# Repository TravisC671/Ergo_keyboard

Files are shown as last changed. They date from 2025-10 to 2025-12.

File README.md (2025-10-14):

# Items:

- Nice!Nano
- [Gateron Low Profile Switches](https://nuphy.com/collections/switches/products/nuphy-cowberry-l45-low-profile-switches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) + hot swap sockets
- [SK6812-E](https://www.adafruit.com/product/4960) LEDs for backlights
- [5050 neo pixels](https://www.adafruit.com/product/1655?srsltid=AfmBOopqWsB4EftkAqg0JuHwXmVD_hztu0RKxe1mnu9E2U61rxwC4aL4) for case lighting

and more that I'll figure out later

[KiCanvas link](https://kicanvas.org/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)

note the footprints are still a work in progress so nothing is final

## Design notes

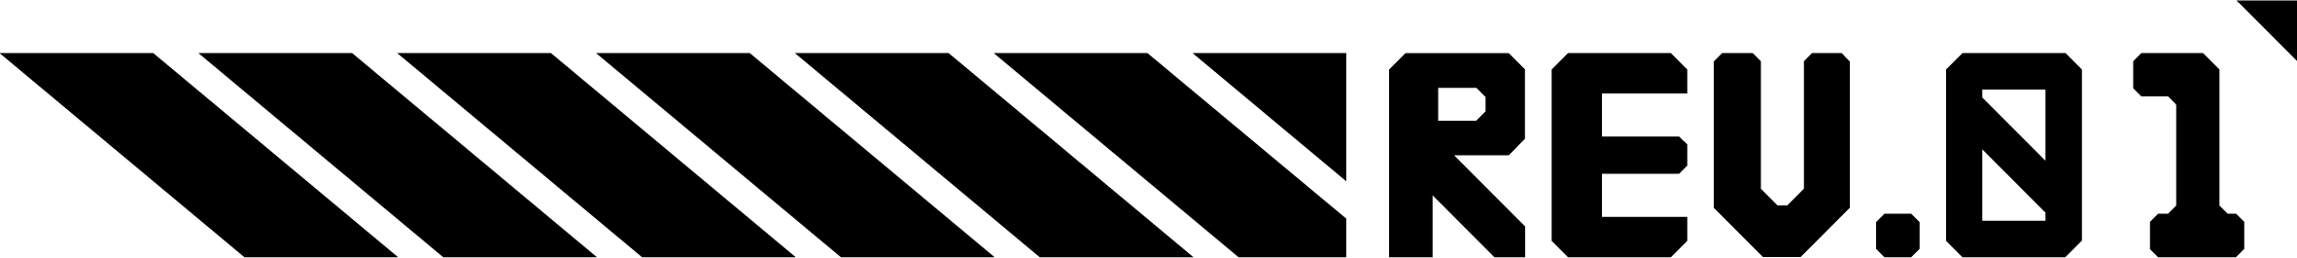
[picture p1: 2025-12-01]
assets/rev_graphic.png

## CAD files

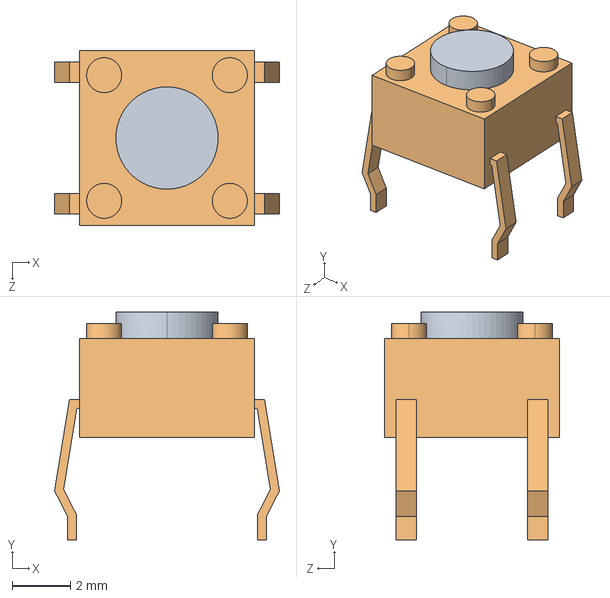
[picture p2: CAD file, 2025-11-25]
ergogen/kicad/B3F_1000/B3F-1000.step
7.70 x 7.80 x 6.00 mm
B3F_1000_BUTTON
B3F_1000_BASE

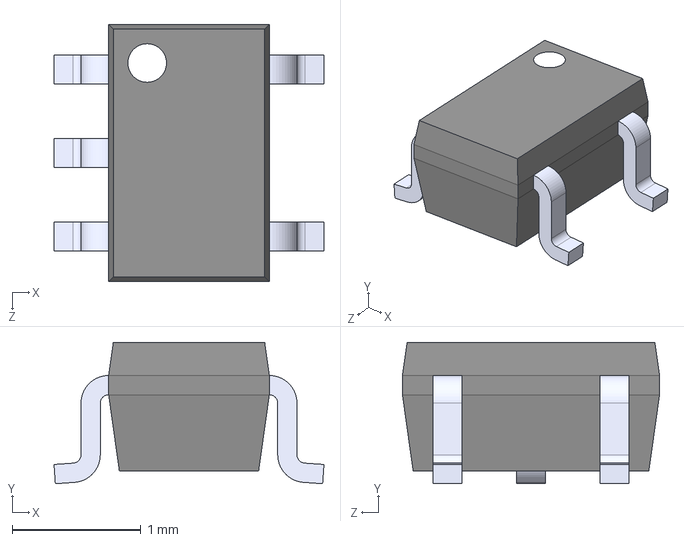
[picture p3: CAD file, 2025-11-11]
ergogen/kicad/SN74LV1T34/SN74LV1T34DCKR.step
2.10 x 1.10 x 2.00 mm

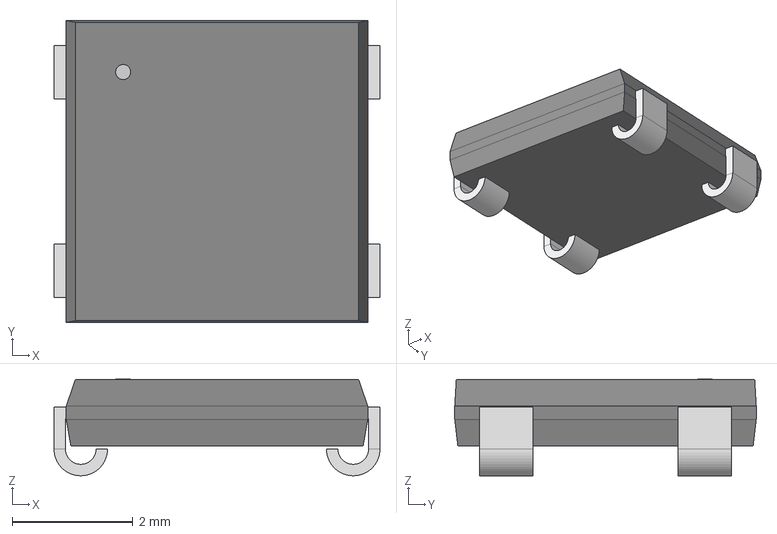
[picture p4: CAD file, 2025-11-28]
ergogen/models/ws2812b.stp
5.41 x 5.00 x 1.60 mm

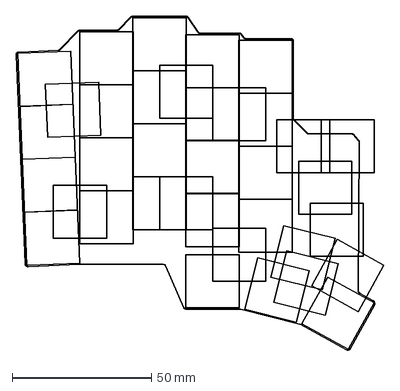
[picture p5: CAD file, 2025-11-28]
output/outlines/view.dxf
131.9 x 119.9 mm

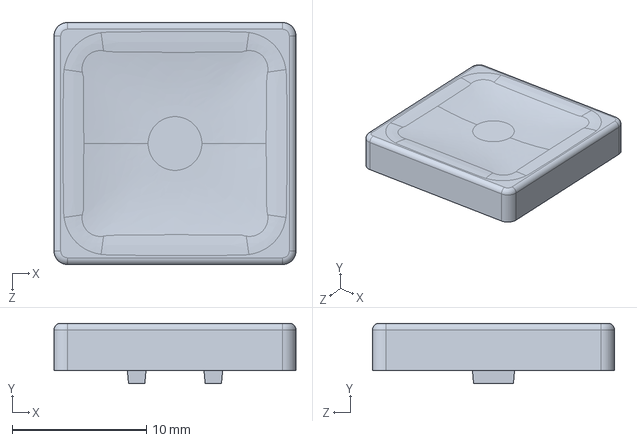
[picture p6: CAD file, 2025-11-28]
ergogen/models/keycap.stp
18.0 x 4.50 x 18.0 mm

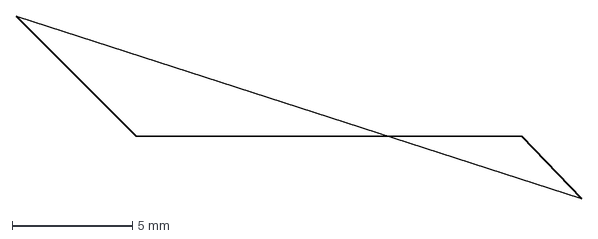
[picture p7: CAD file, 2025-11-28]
output/outlines/mcu_cover.dxf
23.6 x 7.60 mm

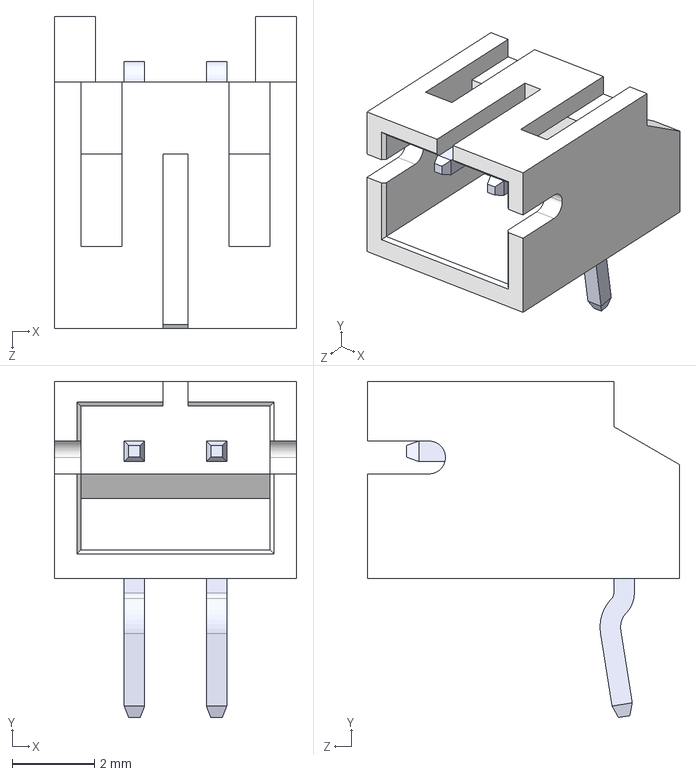
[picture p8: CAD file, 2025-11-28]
ergogen/models/battery_connector.stp
5.90 x 8.18 x 7.60 mm

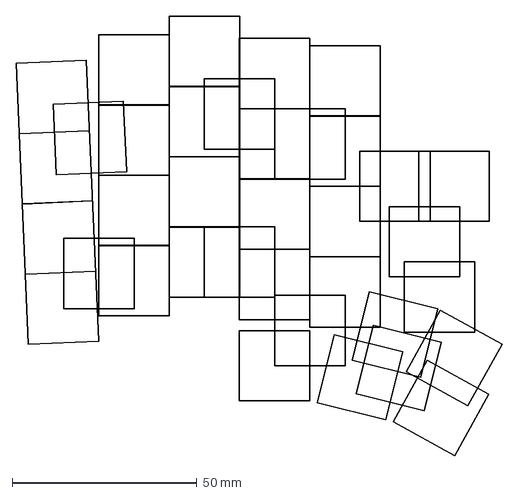
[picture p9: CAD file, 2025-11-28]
output/outlines/keys.dxf
131.4 x 118.9 mm

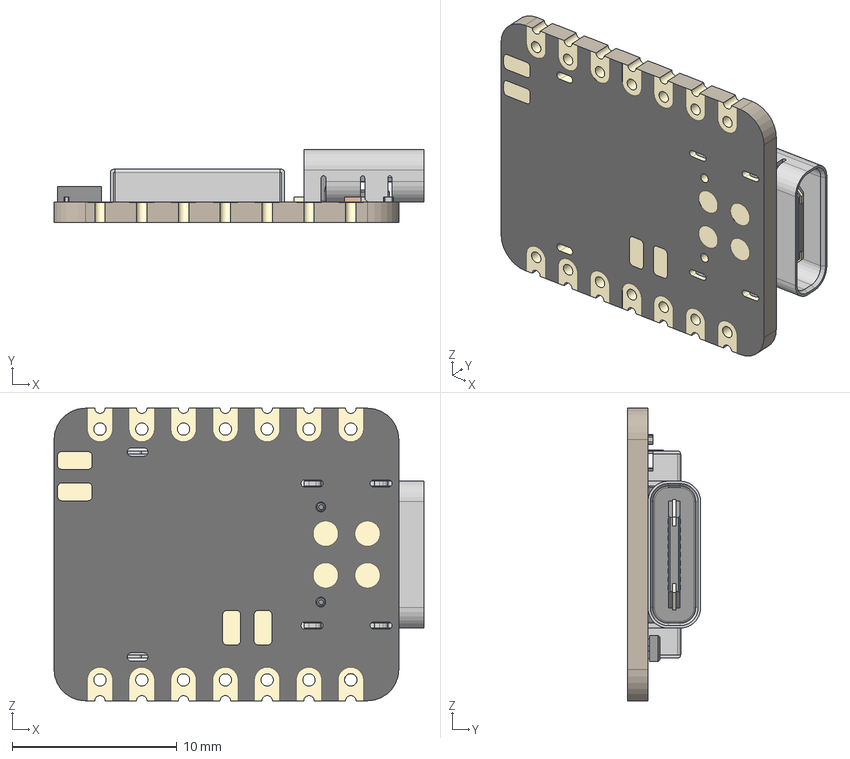
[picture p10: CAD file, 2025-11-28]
ergogen/models/XIAO-nRF52840.stp
22.5 x 4.46 x 17.8 mm
BOSS-EXTRUDE14_8_
BOSS-EXTRUDE7_4_
BOSS-EXTRUDE7_3_
BOSS-EXTRUDE14_4_
BOSS-EXTRUDE14_2_
BOSS-EXTRUDE14_11_
BOSS-EXTRUDE7_7_
BOSS-EXTRUDE14_9_
BOSS-EXTRUDE14_3_
BOSS-EXTRUDE14_7_
MIRROR2
BOSS-EXTRUDE14_5_
BOSS-EXTRUDE14_12_
BOSS-EXTRUDE7_8_
BOSS-EXTRUDE7_1_
BOSS-EXTRUDE14_10_
BOSS-EXTRUDE7_9_
BOSS-EXTRUDE14_6_
BOSS-EXTRUDE14_1_
BOSS-EXTRUDE7_6_
BOSS-EXTRUDE7_2_
CUT-EXTRUDE5
BOSS-EXTRUDE7_5_
Shield
Pins
CAP x 2
ANT1
Silkscreen
CAP 3
LED
USR
2 v1

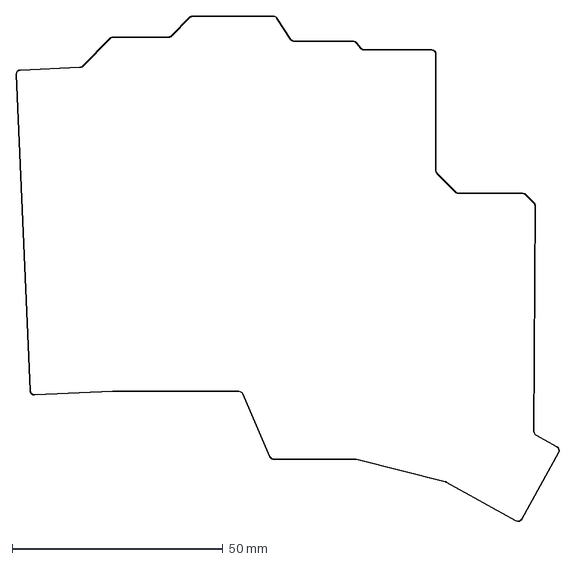
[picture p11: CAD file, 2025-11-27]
output/outlines/pcb_outline.dxf
128.8 x 119.9 mm

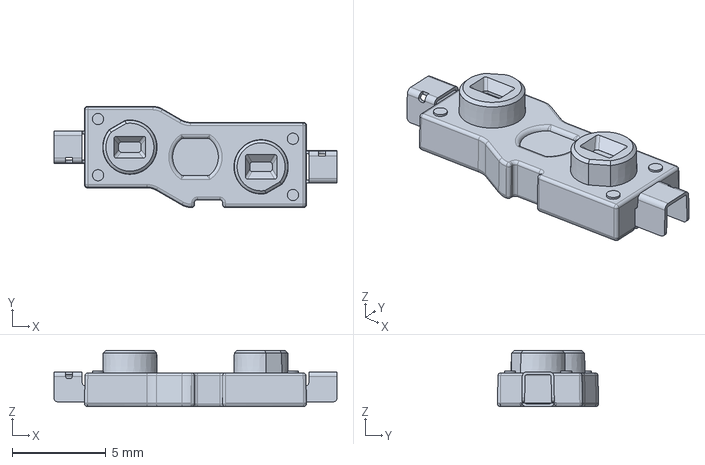
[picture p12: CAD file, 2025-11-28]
ergogen/models/low_profile_hotswap.stp
15.1 x 5.39 x 3.00 mm

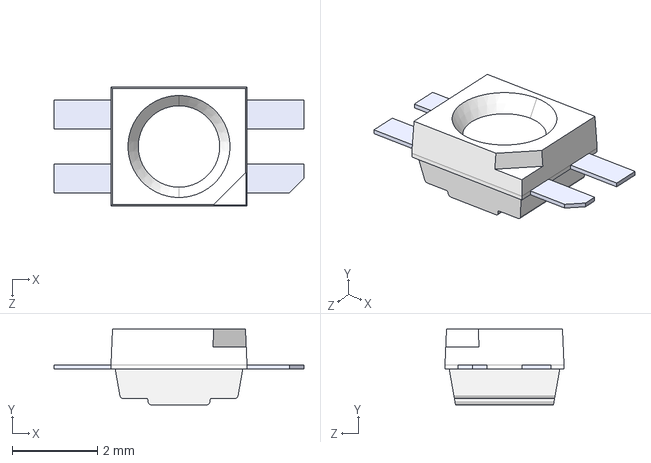
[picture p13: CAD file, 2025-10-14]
ergogen/models/SK6812-E.stp
5.88 x 1.78 x 2.80 mm

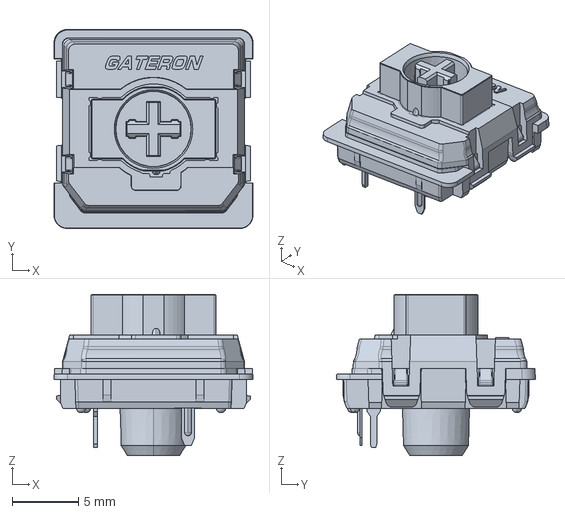
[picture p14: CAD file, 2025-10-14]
ergogen/models/KS-33_lp_2.0.stp
15.0 x 15.0 x 12.1 mm

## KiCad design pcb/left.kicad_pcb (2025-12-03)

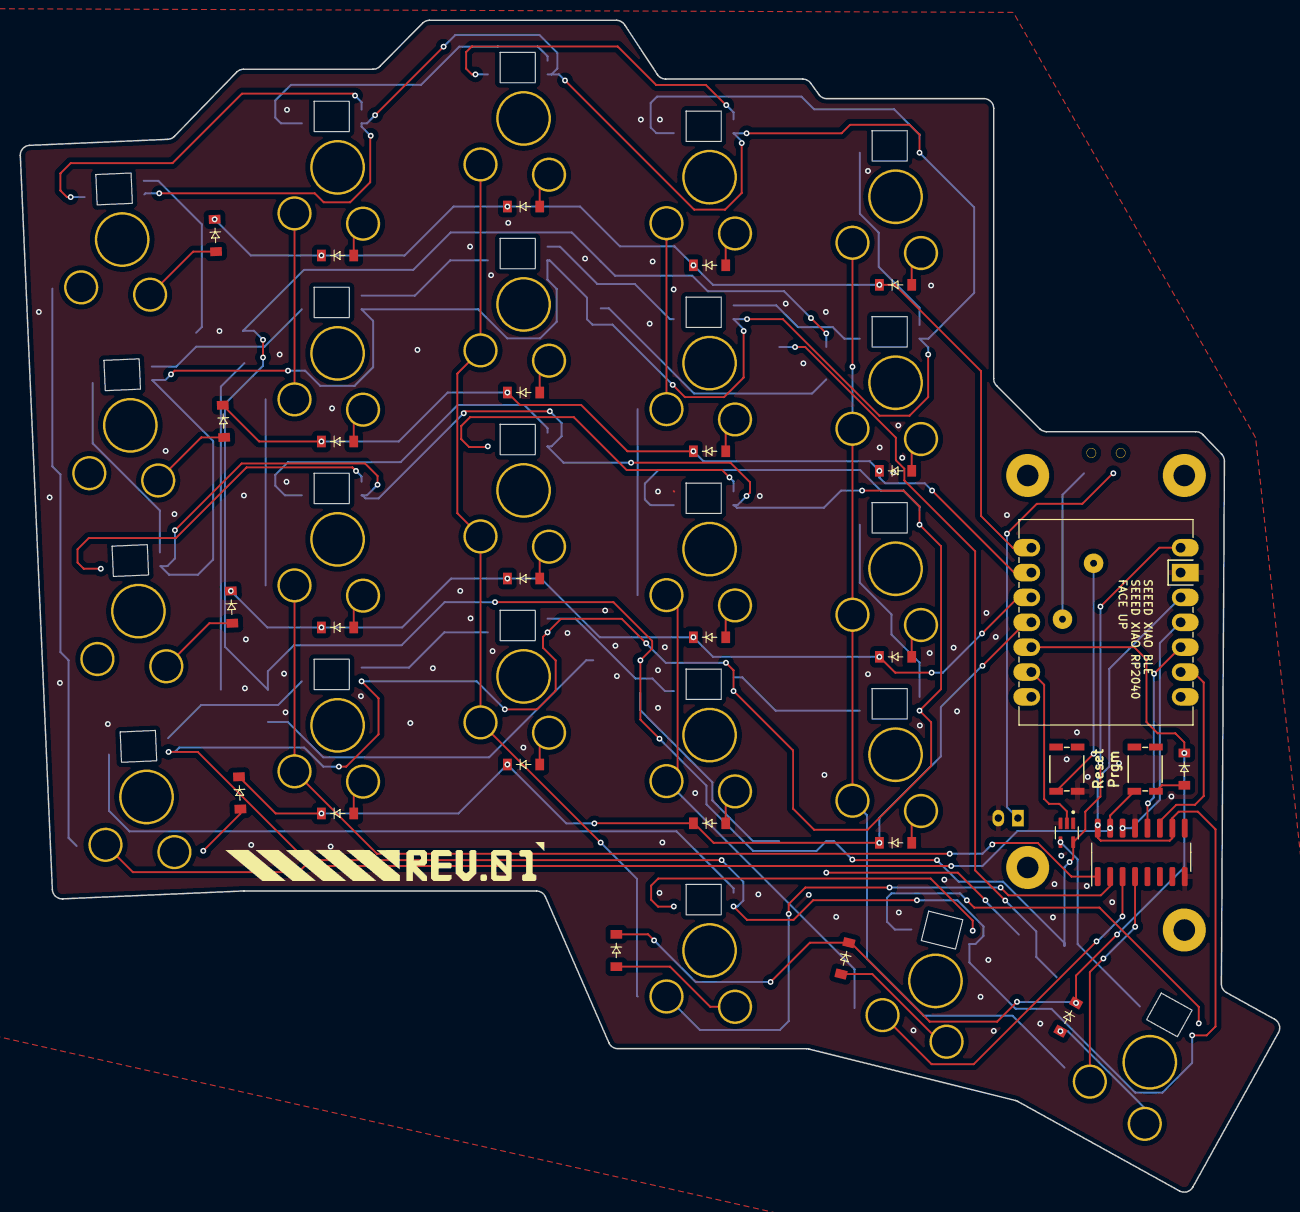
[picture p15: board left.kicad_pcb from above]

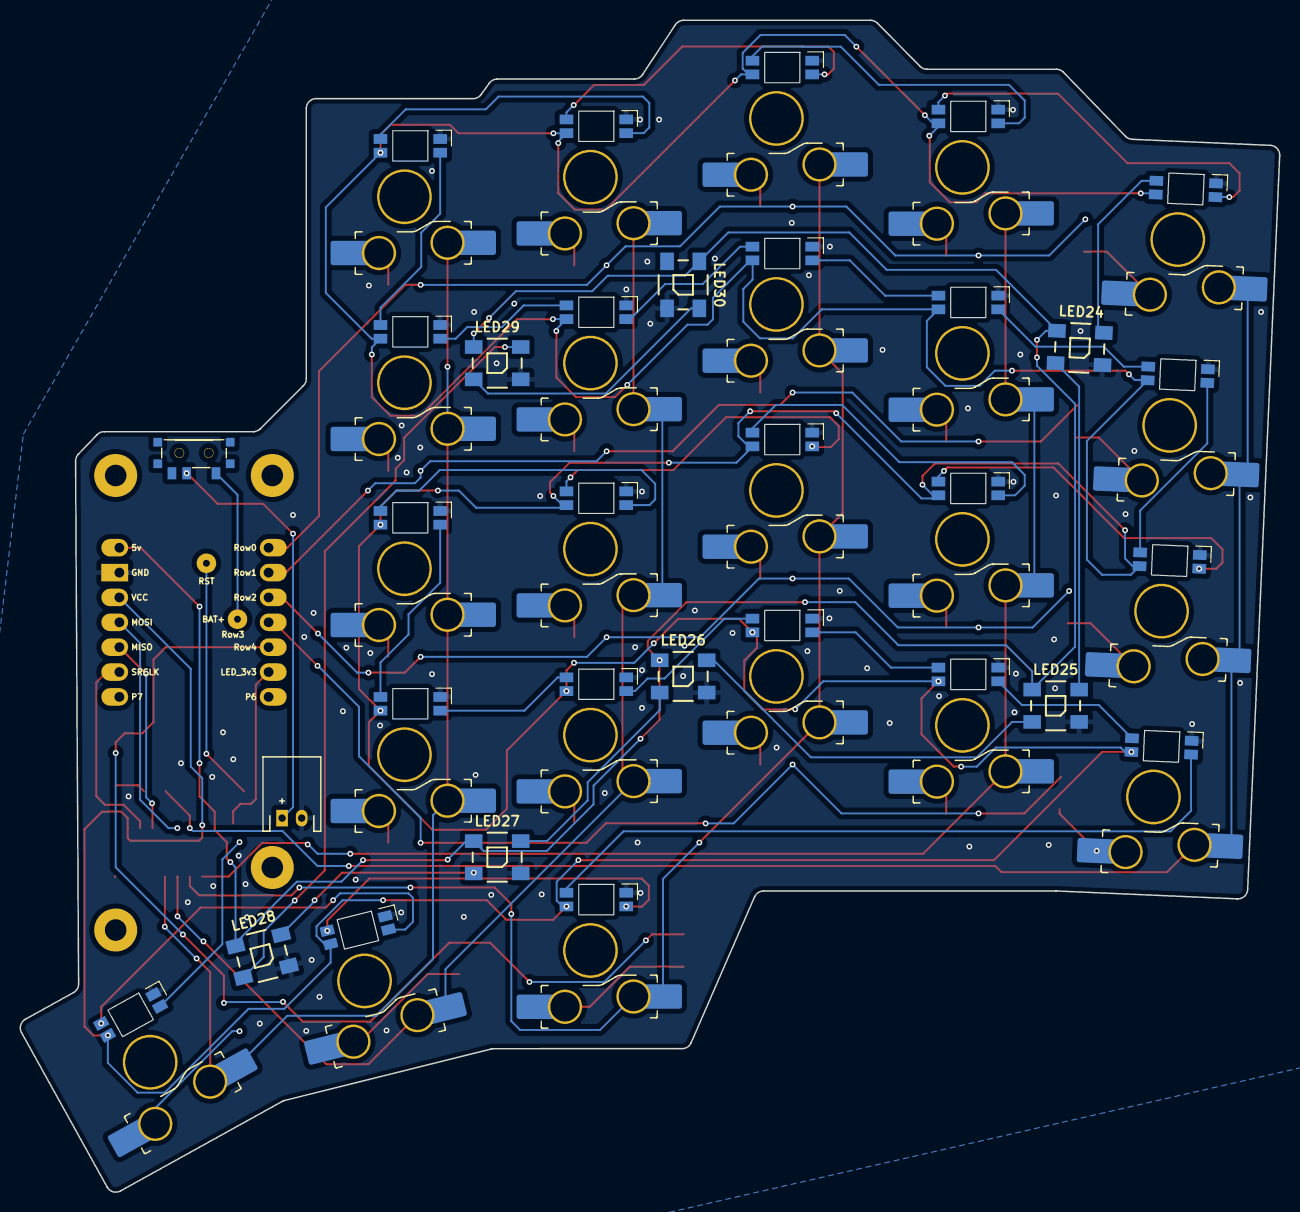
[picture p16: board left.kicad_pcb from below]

Board: 2 copper layers, 128.7 x 119.7 mm, 88 parts (53 on the bottom side), 74 nets.

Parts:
19.051: xiao-ble
19.052: 74HC595; SOIC-16_3.9x9.9mm_P1.27mm
19.053: SOT65P210X110-5N
D1, D2, D3, D4, D5, D6, D7, D8, D9, D10, D11, D12, D13, D14, D15, D16, D17, D18, D19, D20, D21, D22, D23, D24: ComboDiode
JST1: JST_PH_S2B-PH-K_02x2.00mm_Angled
LED1, LED2, LED3, LED4, LED5, LED6, LED7, LED8, LED9, LED10, LED11, LED12, LED13, LED14, LED15, LED16, LED17, LED18, LED19, LED20, LED21, LED22, LED23: led_SK6812mini-e (per-keysingle-side)
LED24, LED25, LED26, LED27, LED28, LED29, LED30: VAL**; WS2812B
PAD1, PAD2, PAD3, PAD4: MountingHole_2.2mm_M2_Pad
SW1, SW2, SW3, SW4, SW5, SW6, SW7, SW8, SW9, SW10, SW11, SW12, SW13, SW14, SW15, SW16, SW17, SW18, SW19, SW20, SW21, SW22, SW23: switch_gateron_ks27_ks33
SW24, SW25: SMD_025816_WRE
T1: SPDT_C128955

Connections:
5v: 19.051.14, 19.053.5, LED24.1, LED25.1, LED26.1, LED27.1, LED28.1, LED29.1, LED30.1
BAT+: 19.051.19, T1.1
BAT_POS: JST1.1, T1.2
Col0: 19.052.15, SW1.1, SW2.1, SW3.1, SW4.1, SW24.4
Col1: 19.052.1, SW5.1, SW6.1, SW7.1, SW8.1
Col2: 19.052.2, SW9.1, SW10.1, SW11.1, SW12.1, SW21.1
Col3: 19.052.3, SW13.1, SW14.1, SW15.1, SW16.1, SW22.1
Col4: 19.052.4, SW17.1, SW18.1, SW19.1, SW20.1, SW23.1
GND: 19.051.13, 19.052.8, 19.052.13, 19.053.3, JST1.2, LED1.3, LED2.3, LED3.3, LED4.3, LED5.3, LED6.3, LED7.3, LED8.3, LED9.3, LED10.3, LED11.3, LED12.3, LED13.3, LED14.3, LED15.3, LED16.3, LED17.3, LED18.3, LED19.3, LED20.3, LED21.3, LED22.3, LED23.3, LED24.3, LED25.3, LED26.3, LED27.3, LED28.3, LED29.3, LED30.3, SW25.2
LED: 19.053.4, LED23.4
LED1: LED22.4, LED23.2
LED2: LED21.4, LED22.2
LED3: LED1.4, LED21.2
LED4: LED1.2, LED5.4
LED5: LED5.2, LED9.4
LED6: LED9.2, LED13.4
LED7: LED13.2, LED17.4
LED8: LED17.2, LED18.4
LED9: LED14.4, LED18.2
LED10: LED10.4, LED14.2
LED11: LED6.4, LED10.2
LED12: LED2.4, LED6.2
LED13: LED2.2, LED3.4
LED14: LED3.2, LED7.4
LED15: LED7.2, LED11.4
LED16: LED11.2, LED15.4
LED17: LED15.2, LED19.4
LED18: LED19.2, LED20.4
LED19: LED16.4, LED20.2
LED20: LED12.4, LED16.2
LED21: LED8.4, LED12.2
LED22: LED4.4, LED8.2
LED_3v3: 19.051.6, 19.053.2
LED_BACKLIGHT_1: LED4.2, LED24.4
LED_BACKLIGHT_2: LED24.2, LED25.4
LED_BACKLIGHT_3: LED25.2, LED26.4
LED_BACKLIGHT_4: LED26.2, LED27.4
LED_BACKLIGHT_5: LED27.2, LED28.4
LED_BACKLIGHT_6: LED28.2, LED29.4
LED_BACKLIGHT_7: LED29.2, LED30.4
MISO: 19.051.10, 19.052.12
MOSI: 19.051.11, 19.052.14
Prgm_diode: D24.2, SW24.2
RST: 19.051.17, SW25.4
Row0: 19.051.1, D4.1, D8.1, D12.1, D16.1, D23.1
Row1: 19.051.2, D3.1, D7.1, D11.1, D15.1, D22.1
Row2: 19.051.3, D2.1, D6.1, D10.1, D14.1, D21.1
Row3: 19.051.4, D1.1, D5.1, D9.1, D13.1, D20.1
Row4: 19.051.5, D17.1, D18.1, D19.1, D24.1
SRCLK: 19.051.9, 19.052.11
VCC: 19.051.12, 19.052.10, 19.052.16, LED1.1, LED2.1, LED3.1, LED4.1, LED5.1, LED6.1, LED7.1, LED8.1, LED9.1, LED10.1, LED11.1, LED12.1, LED13.1, LED14.1, LED15.1, LED16.1, LED17.1, LED18.1, LED19.1, LED20.1, LED21.1, LED22.1, LED23.1
far_thumb: D19.2, SW23.2
home_thumb: D18.2, SW22.2
index_bottom: D9.2, SW13.2
index_home: D10.2, SW14.2
index_number: D12.2, SW16.2
index_top: D11.2, SW15.2
inner_bottom: D13.2, SW17.2
inner_home: D14.2, SW18.2
inner_number: D16.2, SW20.2
inner_top: D15.2, SW19.2
middle_bottom: D5.2, SW9.2
middle_home: D6.2, SW10.2
middle_number: D8.2, SW12.2
middle_top: D7.2, SW11.2
near_thumb: D17.2, SW21.2
pinky_bottom: D20.2, SW1.2
pinky_home: D21.2, SW2.2
pinky_number: D23.2, SW4.2
pinky_top: D22.2, SW3.2
ring_bottom: D1.2, SW5.2
ring_home: D2.2, SW6.2
ring_number: D4.2, SW8.2
ring_top: D3.2, SW7.2

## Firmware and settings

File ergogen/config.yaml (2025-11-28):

meta:
  engine: 4.1.0
units:
  p: 0
  hU: .5U
  hUp: hU + p
  # padding for the case edge
  ep: .5
  mcuY: 5
points:
  zones.key_matrix:
    anchor:
      rotate: 2.5
      shift: [100, -100]
    columns:
      pinky:
        key:
          column_net: Col0
          tags: [key, pinky]
        rows:
          bottom:
            key:
              led_prev: LED3
              led_next: LED4
          home:
            key:
              led_prev: LED12
              led_next: LED13
          top:
            key:
              led_prev: LED13
              led_next: LED14
          number:
            key:
              led_prev: LED22
              led_next: LED_BACKLIGHT_1
      ring:
        key:
          splay: -2.5
          origin: [-12, -19]
          stagger: 7
          column_net: Col1
          tags: [key, main]
        rows:
          bottom:
            key:
              led_prev: LED4
              led_next: LED5
          home:
            key:
              led_prev: LED11
              led_next: LED12
          top:
            key:
              led_prev: LED14
              led_next: LED15
          number:
            key:
              led_prev: LED21
              led_next: LED22
      middle:
        key:
          stagger: 5
          column_net: Col2
          tags: [key, main]
        rows:
          bottom:
            key:
              led_prev: LED5
              led_next: LED6
          home:
            key:
              led_prev: LED10
              led_next: LED11
          top:
            key:
              led_prev: LED15
              led_next: LED16
          number:
            key:
              led_prev: LED20
              led_next: LED21
      index:
        key:
          stagger: -6
          column_net: Col3
          tags: [key, main]
        rows:
          bottom:
            key:
              led_prev: LED6
              led_next: LED7
          home:
            key:
              led_prev: LED9
              led_next: LED10
          top:
            key:
              led_prev: LED16
              led_next: LED17
          number:
            key:
              led_prev: LED19
              led_next: LED20
      inner:
        key:
          stagger: -2
          column_net: Col4
          tags: [key, main]
        rows:
          bottom:
            key:
              led_prev: LED7
              led_next: LED8
          home:
            key:
              led_prev: LED8
              led_next: LED9
          top:
            key:
              led_prev: LED17
              led_next: LED18
          number:
            key:
              led_prev: LED18
              led_next: LED19
    rows:
      bottom:
        row_net: Row3
      home:
        row_net: Row2
      top:
        row_net: Row1
      number:
        row_net: Row0

  zones.key_thumbfan:
    anchor:
      ref: key_matrix_index_bottom
      shift: [0, -22]
    key:
      tags: [key, thumb_fan]
    columns:
      near:
        key:
          column_net: Col2
        rows.thumb.key:
          led_prev: LED2
          led_next: LED3
      home:
        key:
          spread: 21.25
          splay: -14
          origin: [-11.75, -9]
          column_net: Col3
        rows.thumb.key:
          led_prev: LED1
          led_next: LED2
      far:
        key:
          spread: 21.25
          splay: -15
          origin: [-9.5, -9]
          column_net: Col4
        rows.thumb.key:
          led_prev: LED
          led_next: LED1
    rows:
      thumb:
        row_net: Row4

  zones.mcu:
    anchor:
      ref: key_matrix_inner_bottom
      shift: [21.5, 4 + hU]

  zones.key_prgm:
    anchor:
      ref: mcu
      shift: [4, -15]
    key:
      from: Col0
      to: Row4

  zones.mcu_cover_mounting_hole_top_right:
    anchor:
      ref: mcu
      shift: [8, 15]
    key.tags: [mcu_cover_mounting_hole]
  zones.mcu_cover_mounting_hole_top_left:
    anchor:
      ref: mcu
      shift: [-8, 15]
    key.tags: [mcu_cover_mounting_hole]
  zones.mcu_cover_mounting_hole_bottom_right:
    anchor:
      ref: key_thumbfan_far_thumb
      shift: [-3.466, hUp + 4]
    key.tags: [mcu_cover_mounting_hole]
  zones.mcu_cover_mounting_hole_bottom_left:
    anchor:
      ref: key_thumbfan_home_thumb
      shift: [6.338, hUp + 4]
    key.tags: [mcu_cover_mounting_hole]

  zones.backlight_led_1:
    anchor:
      ref: key_matrix_pinky_top
      shift: [hUp, 7.5]
    key:
      led_prev: LED_BACKLIGHT_1
      led_next: LED_BACKLIGHT_2
      tags: [backlight_led]

  zones.backlight_led_2:
    anchor:
      ref: key_matrix_ring_bottom
      shift: [-hUp, 2]
    key:
      led_prev: LED_BACKLIGHT_2
      led_next: LED_BACKLIGHT_3
      tags: [backlight_led]

  zones.backlight_led_3:
    anchor:
      ref: key_matrix_middle_bottom
      shift: [hUp, 0]
    key:
      led_prev: LED_BACKLIGHT_3
      led_next: LED_BACKLIGHT_4
      tags: [backlight_led]
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

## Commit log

2025-10-12 making more progress, going to redesign some things
    [case.dxf, keys.dxf, left.kicad_pcb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]
2025-10-13 getting closer to a design I like
    [keys.dxf, left.kicad_pcb, pcb_outline.dxf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]
2025-10-13 gonna change outline. wanted to commit before destroying it
    [keys.dxf, left.kicad_pcb, pcb_outline.dxf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]
2025-10-14 super happy with how this is turning out
    current todos:
    - Back lights
    - Battery
    - Name (FLotilla?)
    - inter-communications between halves
    - routing...
    [KS33.stp, SK6812-E.step, left.kicad_pcb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]
2025-10-29 changed profile of mcu outline
    [case.dxf, keys.dxf, left.kicad_pcb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]
2025-11-03 moving to seeed nrf52840 bc of rgb. footprint pretty much done
    [ergo_keyboard.kicad_pcb, left.kicad_pcb]
2025-11-03 working on schematic
    [ergo_keyboard.kicad_sch]
2025-11-04 still working on schematic
    [ergo_keyboard.kicad_sch]
2025-11-04 finishing up schematic
    [ergo_keyboard.kicad_sch]
2025-11-04 1st iteration of schematic done
    [ergo_keyboard.kicad_sch]
2025-11-05 fixed up schematic
    [ergo_keyboard.kicad_sch]
2025-11-06 added usb interconnect for backlights
    [ergo_keyboard.kicad_sch, power_logic.kicad_sch]
2025-11-07 Resturctured and moving to non-reversible pcb
    [ergo_keyboard.kicad_pcb, ergo_keyboard.kicad_sch, left.kicad_pcb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]
2025-11-09 starting to work on the ergogen side again
    [left.kicad_pcb, left.kicad_sch]
2025-11-11 pushing to github
    [KS33.stp, SK6812-E.step, SN74LV1T34DCKR.step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]
2025-11-15 pushing code. gonna rename it to uni-corne
    [left.kicad_pcb]
2025-11-15 almost done with the left side!
    [keys.dxf, left.kicad_pcb, pcb_outline.dxf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]
2025-11-25 sooo close
    [B3F-1000.step, keys.dxf, left.kicad_pcb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]
2025-11-25 changed pinky layout a bit, almost there!!
    [keys.dxf, left.kicad_pcb, pcb_outline.dxf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]
2025-11-26 close to finishing layout/placement
    [keys.dxf, left.kicad_pcb, pcb_outline.dxf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]
2025-11-27 SOO CLOSE
    [left.kicad_pcb, left.kicad_sch, pcb_outline.dxf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]
2025-11-28 trying to make mcu_cover
    [KS-33_lp_2.0.stp, KS33.stp, SK6812-E.step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]
2025-12-01 routing pcb, gotta try restarting
    [left.kicad_pcb]
2025-12-01 gonna start working on the ground plane
    [left.kicad_pcb]
2025-12-01 RAAAAH I AM VICTORIOUS
    [left.kicad_pcb]
2025-12-01 removed old files
    [ergo_keyboard.kicad_pcb, ergo_keyboard.kicad_sch, power_logic.kicad_sch]
2025-12-01 added graphic
    [left.kicad_pcb]
2025-12-03 working on revision
    [left.kicad_pcb]
